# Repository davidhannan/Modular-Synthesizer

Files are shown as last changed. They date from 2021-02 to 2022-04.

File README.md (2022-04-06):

# Modular-Synthesizer

A DIY modular synthesizer.

Made from module circuit designs found from various places online.

Full List of Modules used: [Modules](https://github.com/davidhannan/Modular-Synthesizer/tree/main/Modules) (WIP)

Panel designs made by me in fusion 360 for my 2"x8" module format.
Panels are made from 2"x8"x1/8" aluminum flat bar blanks.

## Update March 24, 2022

How the whole system looks nowadays:


For some reason I thought it would be great if I could start adapting euro modules into my system. Doing so has been quite an adventure in learning how to solder SMD components and learning how to flash a program onto a microcontroller, and to be honest it hasn't been so bad. I actually learned to enjoy it quite a bit! The first one I made was the <a href="https://ornament-and-cri.me/">Ornament and crime</a> which went together pretty smoothly and even started working right away! It can be seen at the very bottom right of the system shot. Next I went for a <a href="https://mutable-instruments.net/modules/braids/">Mutable Instruments Braids</a>. This one wasn't quite as easy as the OC, but I got it working in the end! The main issue I encountered was that I didn't realize that since the PCB that I ordered ended up being for an older version of the module, I had to provide my own +5 volt source to the module along with the +/- 12v that most modules normally require. I ended up throwing together a small 5v regulator using a 7805 and a few capacitors on a piece of stripboard which I hot-glued to the back of board.

Some pictures of the Braids module:



This one shows the 5v regulator that I had to make:


I also have been getting pretty good etching my own PCBs. Heres one for a <a href="http://yusynth.net/Modular/EN/METALIZER/">Yusynth Metalizer</a> that I finished recently. It wasn't finished in the picture but I think it looks great!





## Update February 17, 2022

I never did end up making that fancy cabinet, but I did make two more of the square ones! I filled out one of them and I'm still working on the other. So many new modules in here, too many to list right now. I'll get around to it at some point I'm sure. I even got into some surface mount stuff in here. 

Here is a picture of two full cabinets, featuring my keystep pro sequencer, tape machine/headphone tube amp, and a <a href="https://github.com/davidhannan/Akai-M8-Pre-Mod">mic/guitar pre amp</a> I just finished up.



The inside of cabinet number 2.



## Update June 21, 2021:

The cabinet for stage 2 of my synth system has been designed and it will be made soon. Stage 1 will stack on top of stage 2 for a very cool look. Here is what stage 2 will look like:

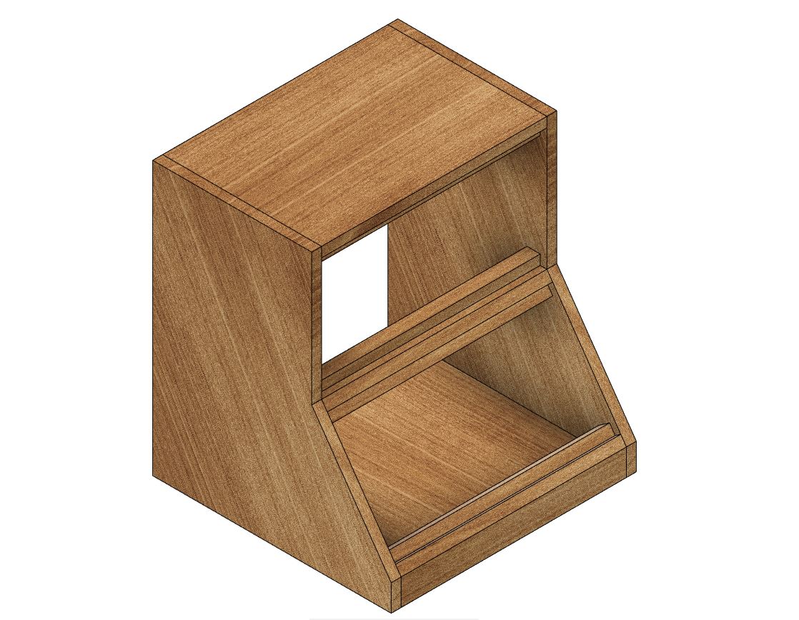
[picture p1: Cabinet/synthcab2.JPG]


## Update June 3, 2021:

Stage 1 is complete! Some pictures of the finished product:











## New as of March 16, 2021:  
Barton Quad VCA Mixer:  
  
PCB purchased from synthcube

## State as of March 8, 2021:  


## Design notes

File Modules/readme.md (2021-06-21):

# List of Modules in Stage 1:

1. 3x VCO from Eddy Bergman. [Link](https://www.eddybergman.com/2020/01/synthesizer-build-part-18-really-good.html)

2. ADSR from Eddy Bergman. [Link](https://www.eddybergman.com/2020/03/synthesizer-build-part-24-adsr-with.html)

3. VCA from Eddy Bergman. [Link](https://www.eddybergman.com/2020/04/synthesizer-build-part-29-vca-yusynth_25.html)

4. Gate/CV Multiple from Eddy Bergman. [Link](https://www.eddybergman.com/2020/03/synthesizer-build-part-25-universal-cv.html)

5. Mixer with passive output from Eddy Bergman. [Link](https://www.eddybergman.com/2020/01/synthesizer-build-part-17-mixer-and.html)

6. VCLFO from Eddy Bergman. [Link](https://www.eddybergman.com/2020/05/synthesizer-build-part-32-electric.html)

7. MS-20 type filter from Eddy Bergman. [Link](https://www.eddybergman.com/2019/12/synthesizer-build-part-12-korg-ms20.html)

8. Resonant Lopass gate from Eddy Bergman. [Link](https://www.eddybergman.com/2020/10/synthesizer-build-part-35-resonant.html)

9. "Safety Valve" from Look Mum No Computer. [Link](https://www.lookmumnocomputer.com/projects#/the-safety-valve)

10. Juno Chorus and Sub Oscillator Combo Module (these are seperate modules but I put them behind the same panel) . [Chorus Link](https://www.dsl-man.de/display/MAIN/Roland+Juno+60+Chorus) | [Sub Osc Link](https://github.com/holmesrichards/subosc)

11. Another multiple module "Euro Multipla" from SyntherJack. I made 2 of these boards, using all ins/outs of one of them and only half of the second one. [Link](https://syntherjack.net/euro-multipla/)

12. Mixer/VCA from Michael Barton. [Link](http://www.bartonmusicalcircuits.com/vcamix/index.html)

13. Simple A/R from Michael Barton. [Link](http://www.bartonmusicalcircuits.com/simplear/index.html)

14. Moog Ladder Filter from Yusynth. [Link](http://yusynth.net/Modular/EN/MOOGVCF/index.html)

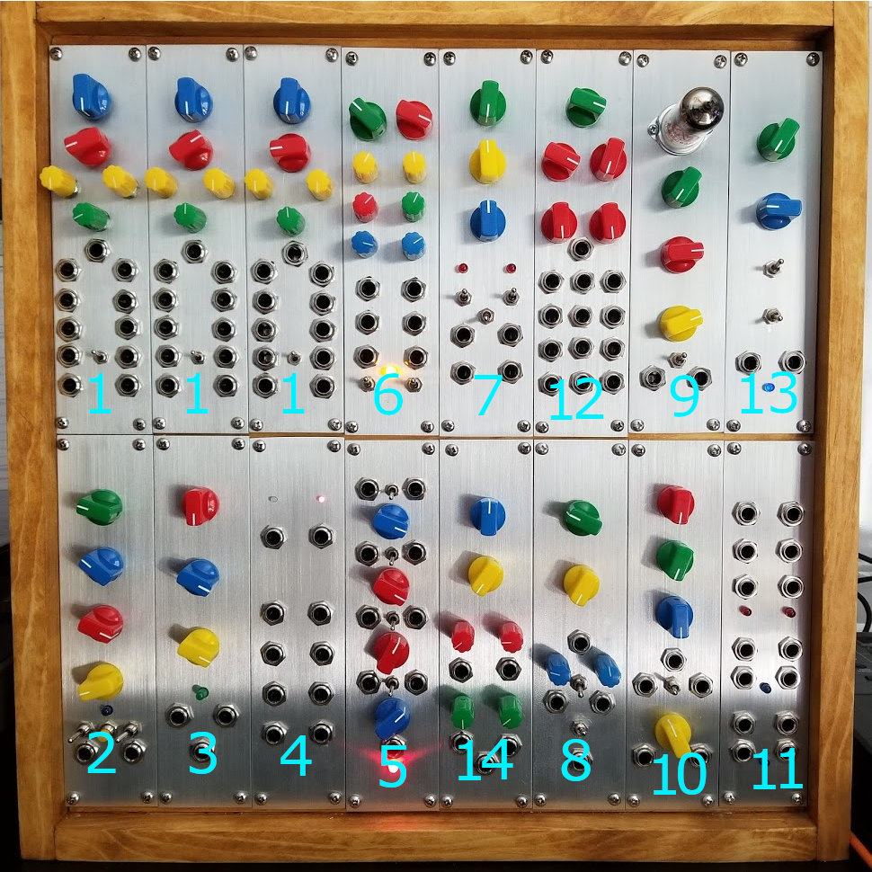
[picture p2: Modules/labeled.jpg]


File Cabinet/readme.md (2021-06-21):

Empty Cabinet:

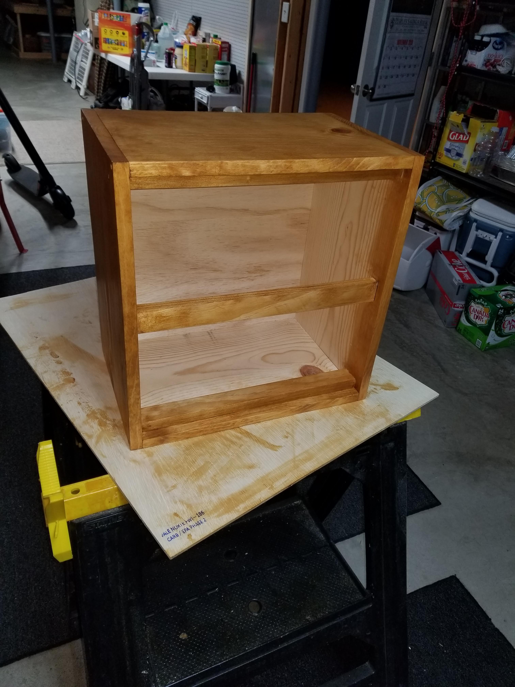
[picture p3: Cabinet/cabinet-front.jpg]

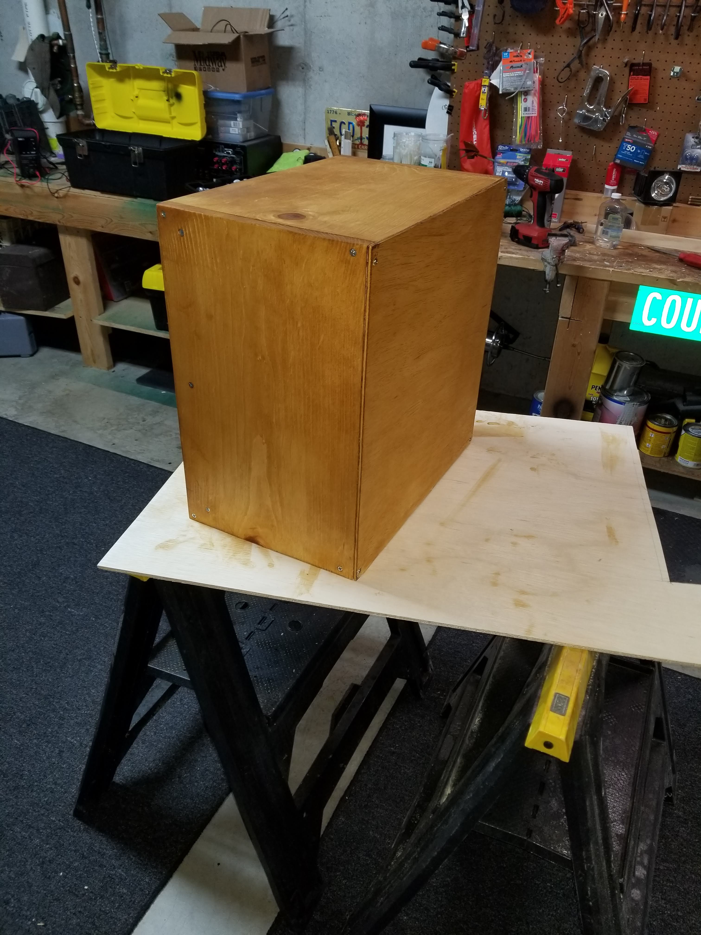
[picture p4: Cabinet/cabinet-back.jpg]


Stage 2 Cabinet CAD:



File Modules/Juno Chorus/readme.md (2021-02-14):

Details of this module can be found <a href="https://www.dsl-man.de/display/MAIN/Roland+Juno+60+Chorus">here</a>

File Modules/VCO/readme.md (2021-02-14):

Empty VCO Panels:

A brushed aluminum finish is achieved by sanding in a jig to ensure uniform sanding direction. An acrylic spray sealant is then applied.

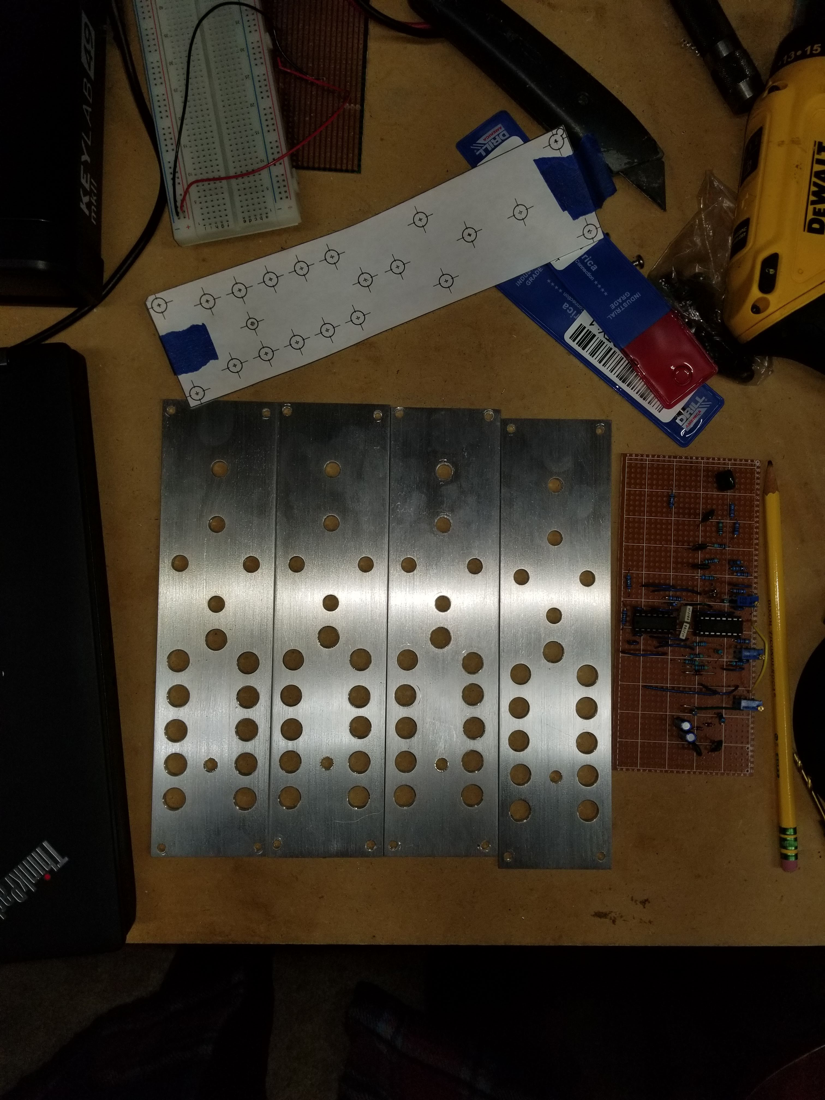
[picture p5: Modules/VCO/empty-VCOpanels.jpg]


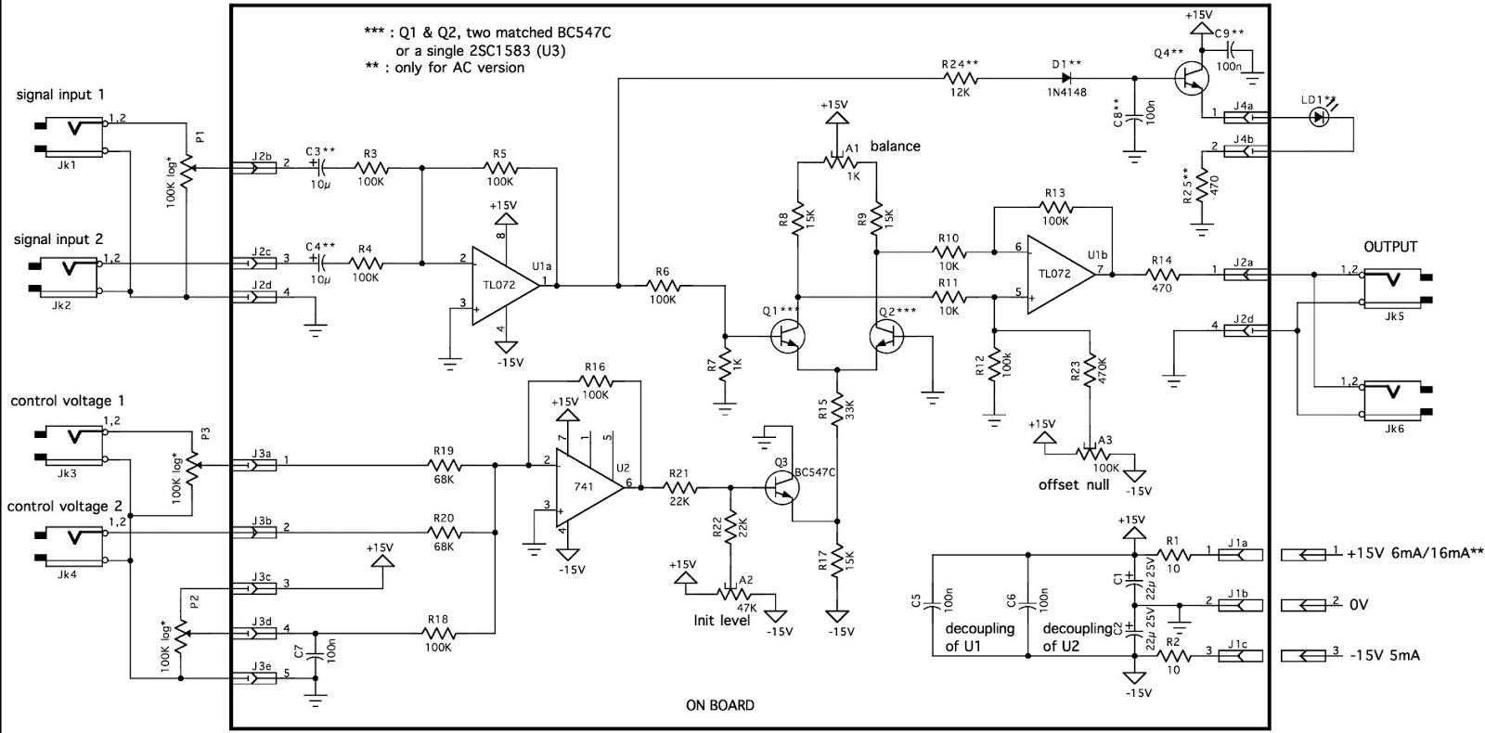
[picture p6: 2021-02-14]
Modules/VCA/VCA Yusynth design new.jpg

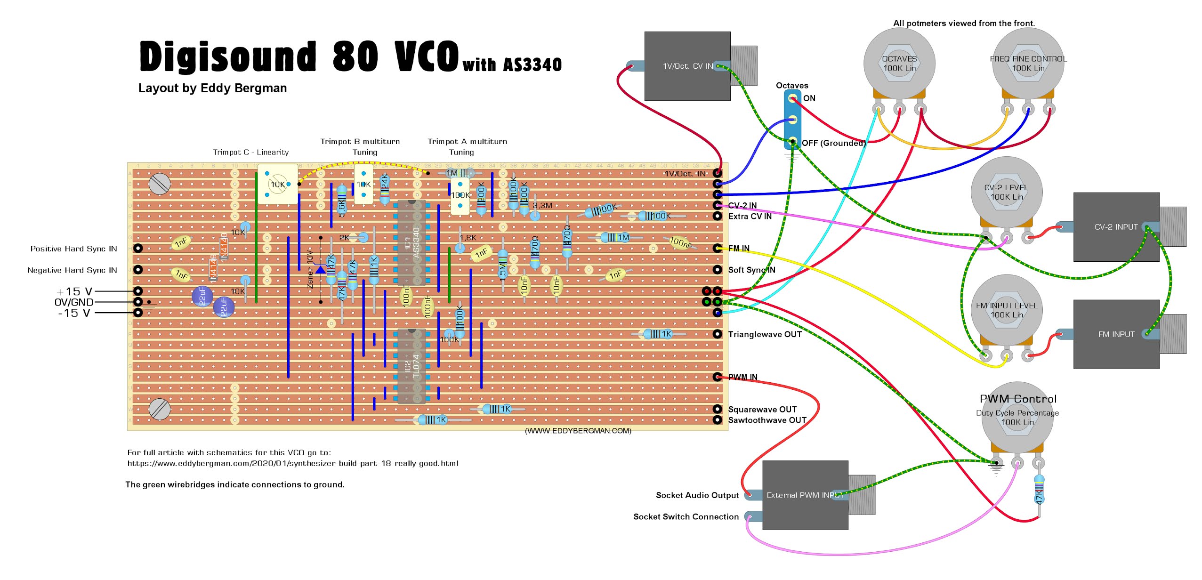
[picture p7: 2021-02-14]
Modules/VCO/Digisound 80 VCO latest w PWM correction.jpg

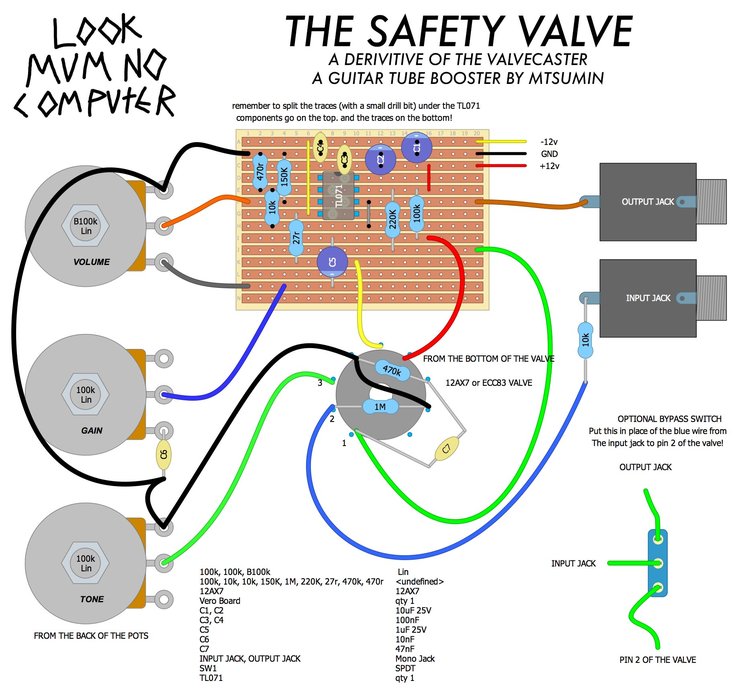
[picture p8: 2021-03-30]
Modules/LMNC safety valve/The+Safety+Valve+Synth+Module.jpg

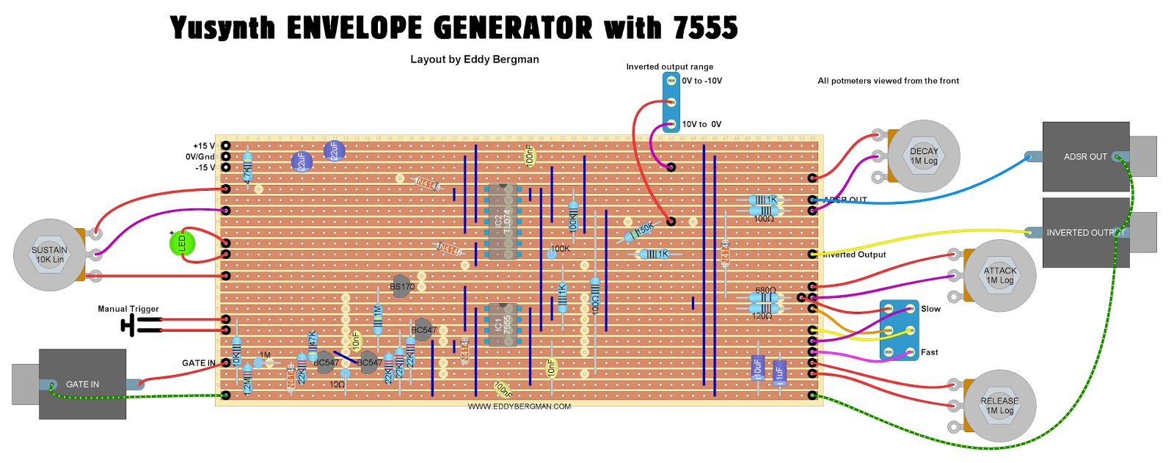
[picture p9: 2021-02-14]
Modules/ADSR/Yusynth ADSR with 7555.jpg

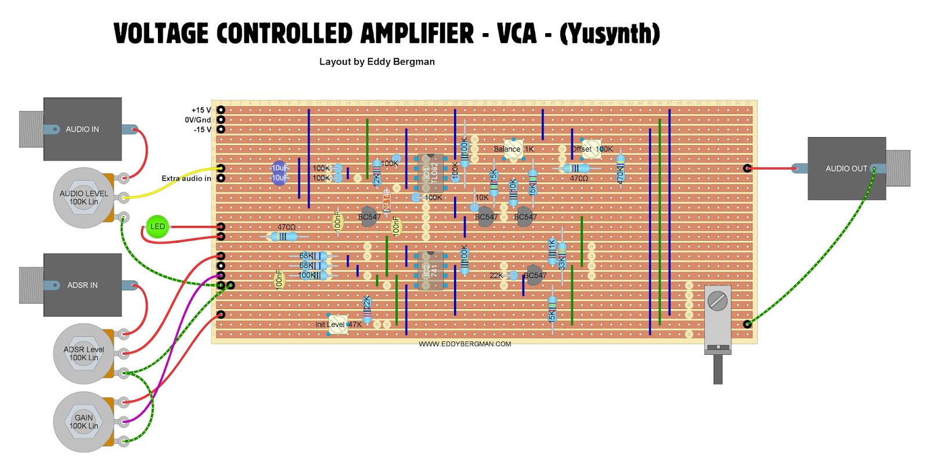
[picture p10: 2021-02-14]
Modules/VCA/VCA-04 yusynth.jpg

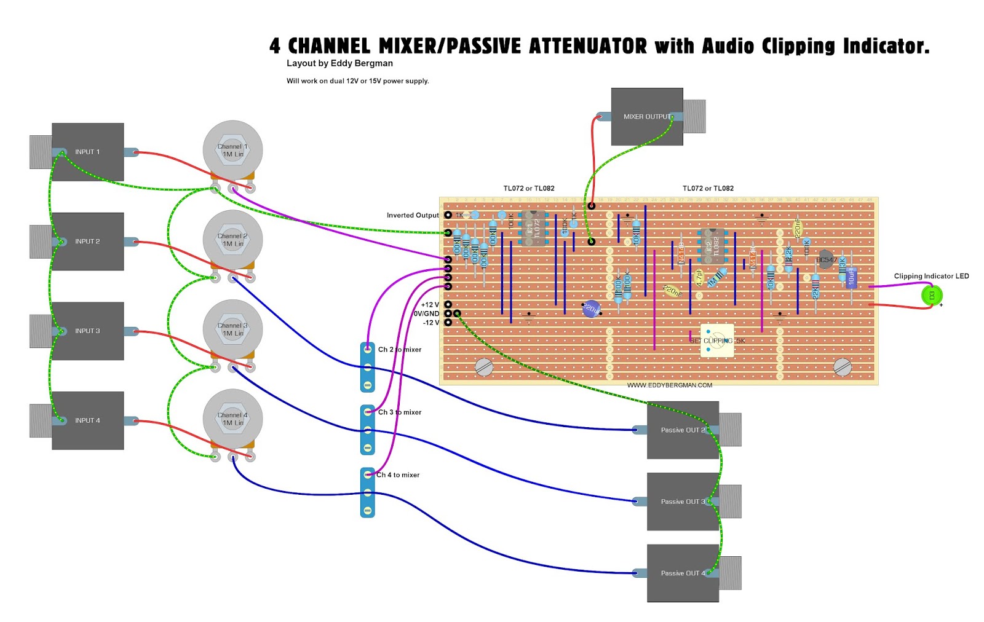
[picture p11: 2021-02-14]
Modules/Mixer/4 Channel Mixer with Clipping Indicator.jpg

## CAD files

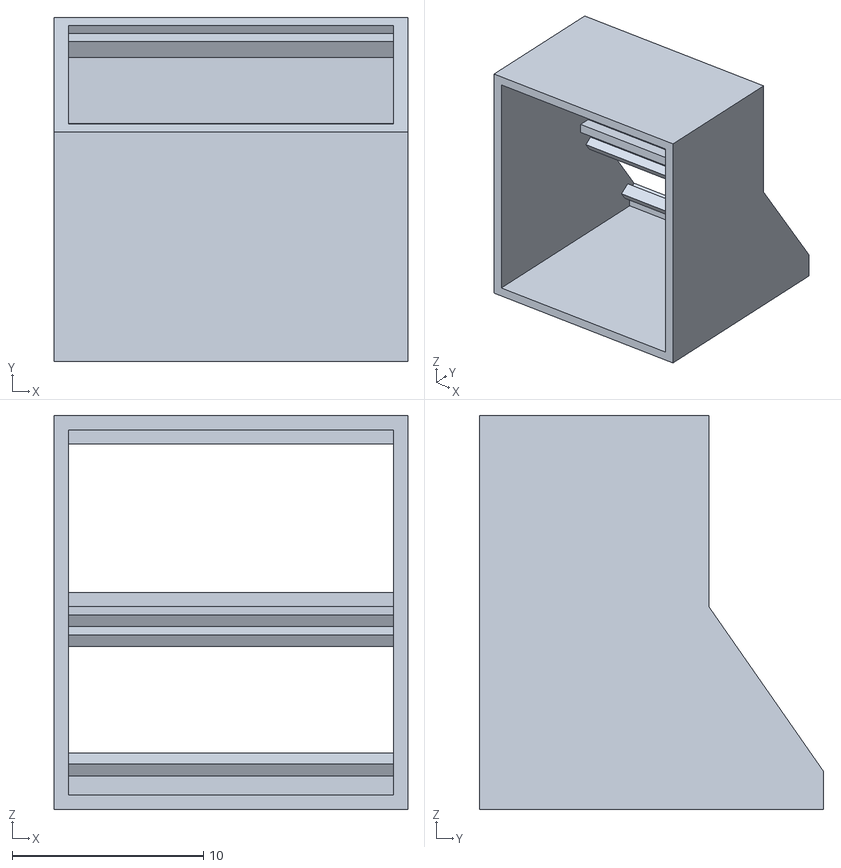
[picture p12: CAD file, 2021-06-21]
Cabinet/cab part 2 comps v3.stl
18.5 x 18.0 x 20.6

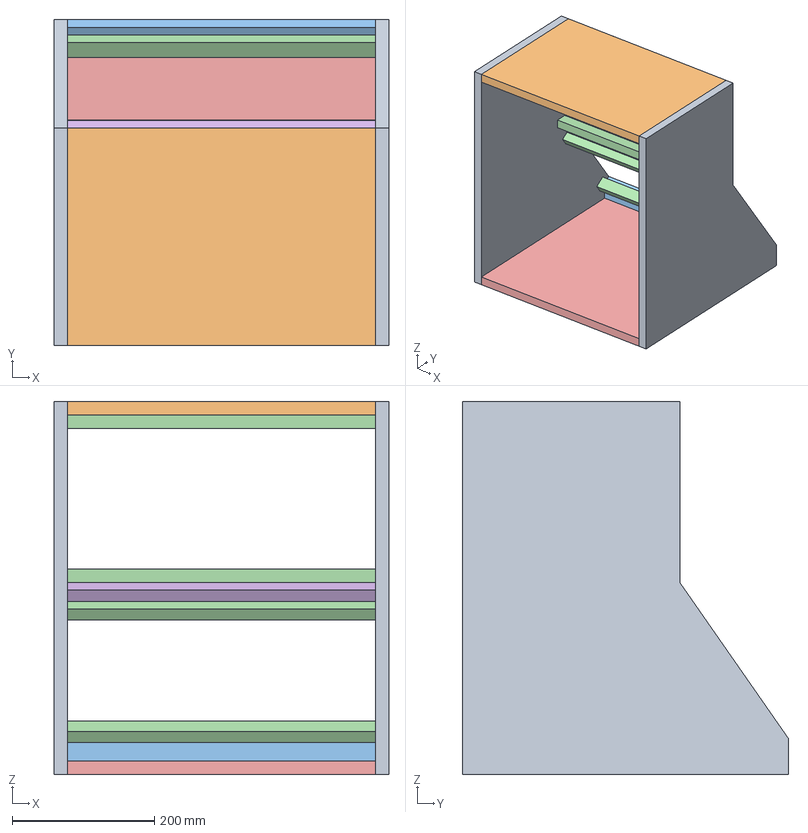
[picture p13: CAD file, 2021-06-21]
Cabinet/synthcabinet2.step
469.9 x 457.2 x 523.7 mm
Right Side
Top
Left Side
Front
Upper Module Section Top Mount
Upper Module Section Bottom Mount
Lower Module Section Top Mount
Lower Module Section Bottom Mount
Bottom
Section Divider

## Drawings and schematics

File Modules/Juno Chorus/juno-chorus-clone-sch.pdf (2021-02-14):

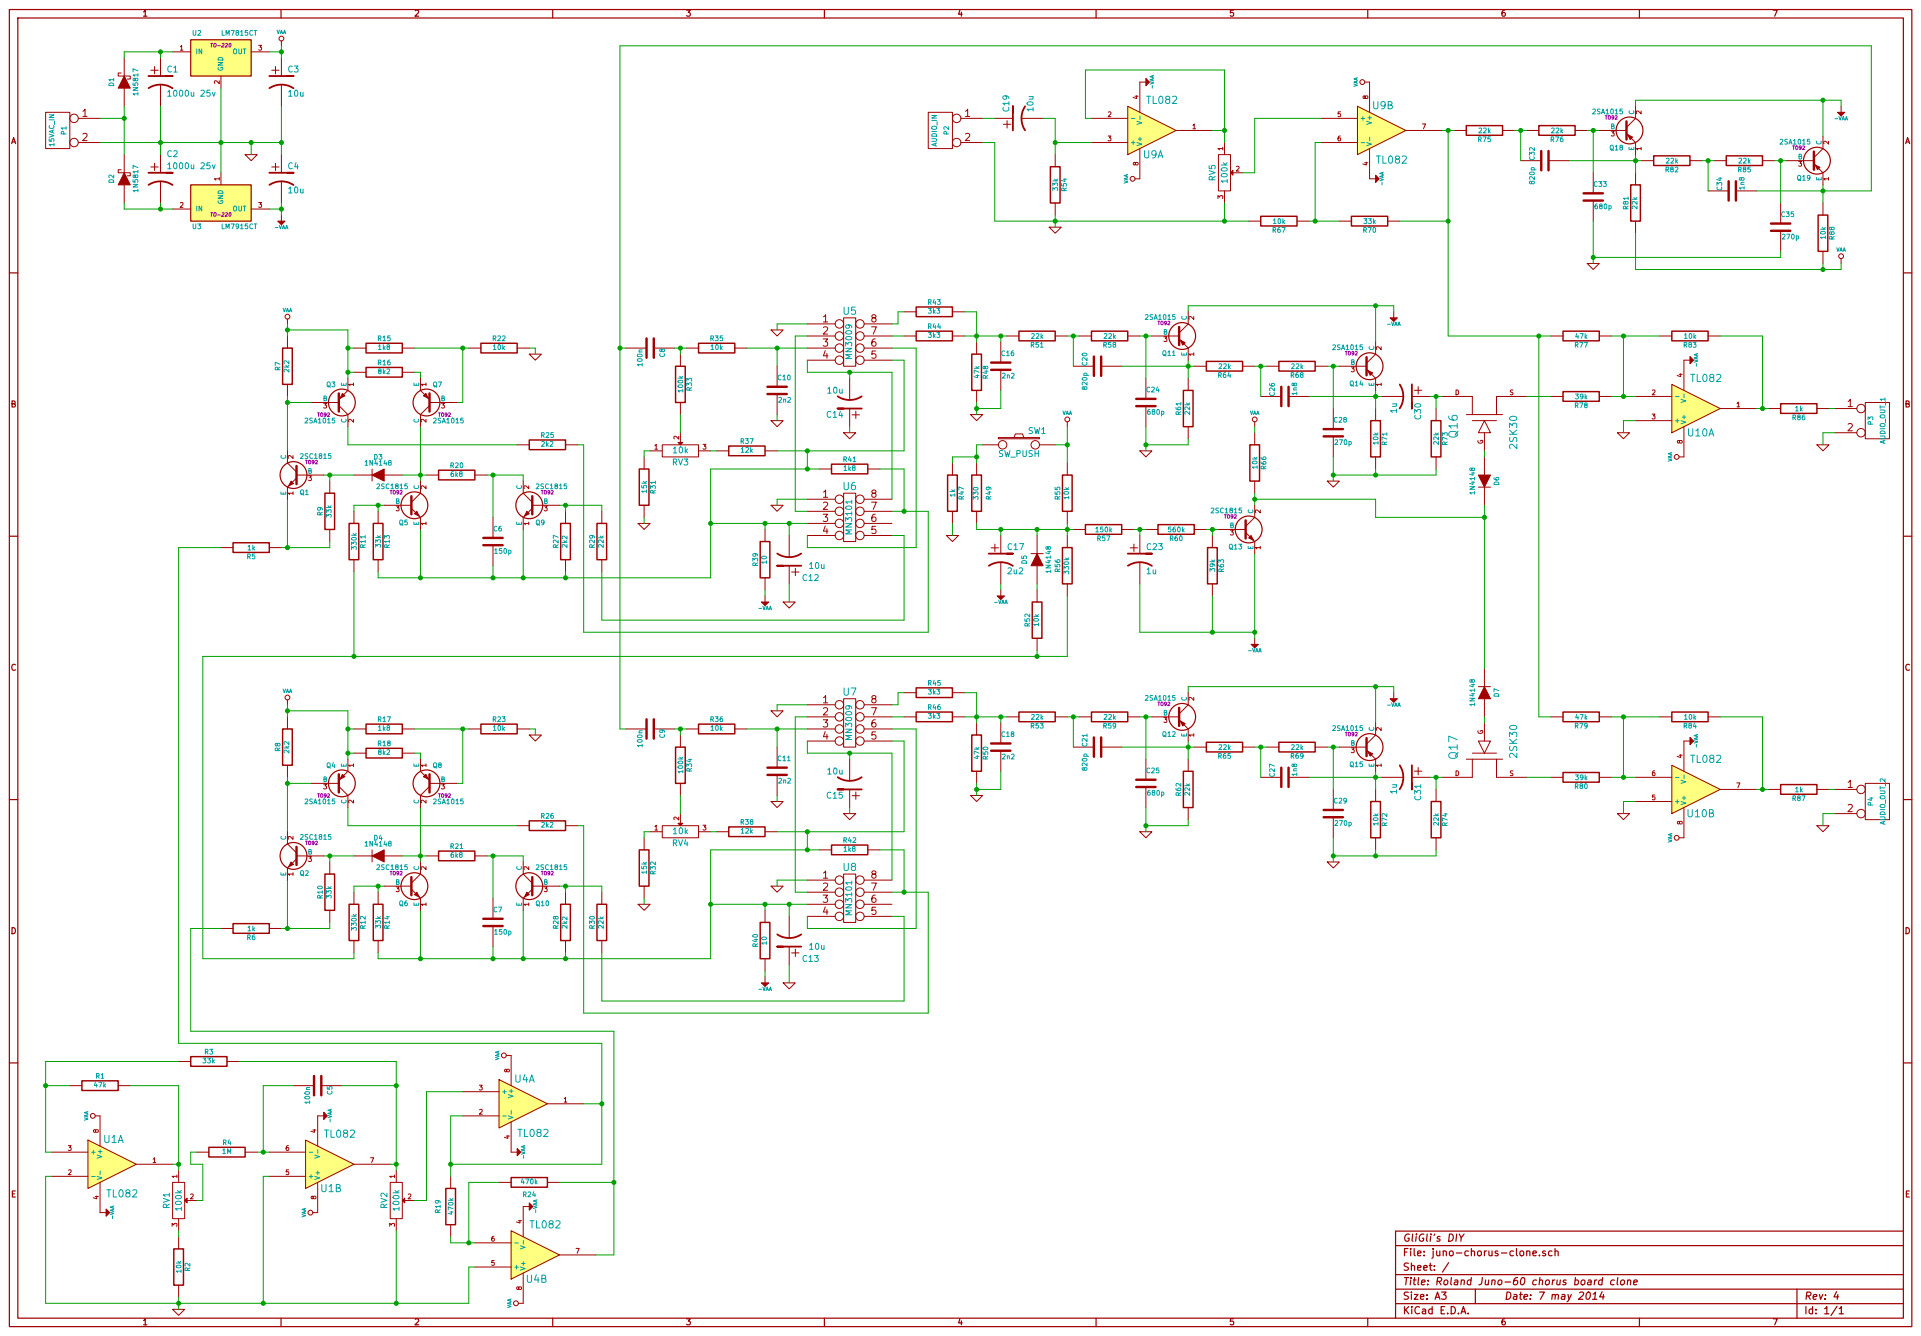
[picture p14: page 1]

GliGli's DIY
Id: 1/1 Title: Roland Juno-60 chorus board clone File: juno-chorus-clone.sch
Sheet: /

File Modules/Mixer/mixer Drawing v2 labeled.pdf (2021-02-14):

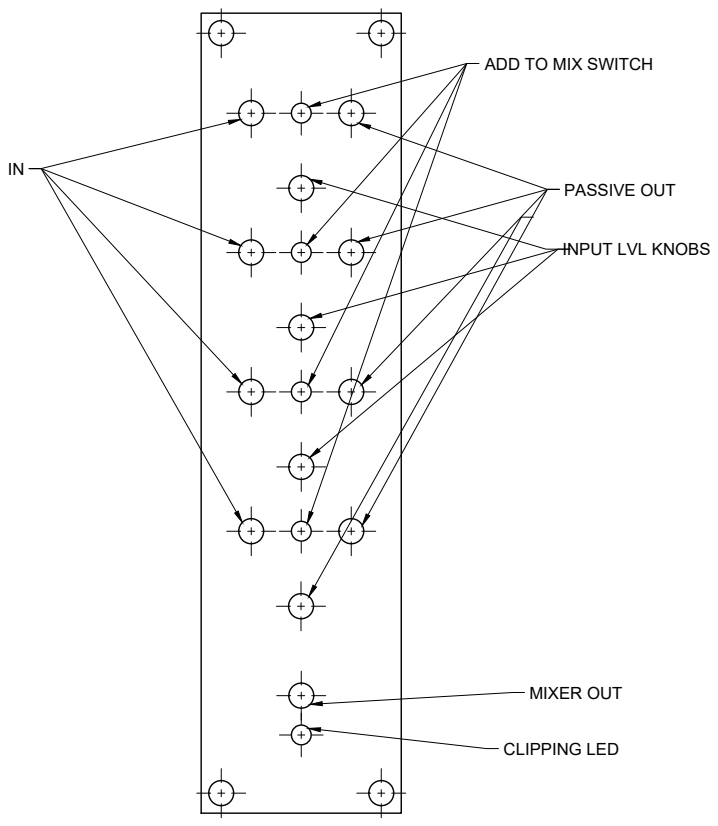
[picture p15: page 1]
PASSIVE OUT; MIXER OUT; CLIPPING LED

ADD TO MIX SWITCH

INPUT LVL KNOBS

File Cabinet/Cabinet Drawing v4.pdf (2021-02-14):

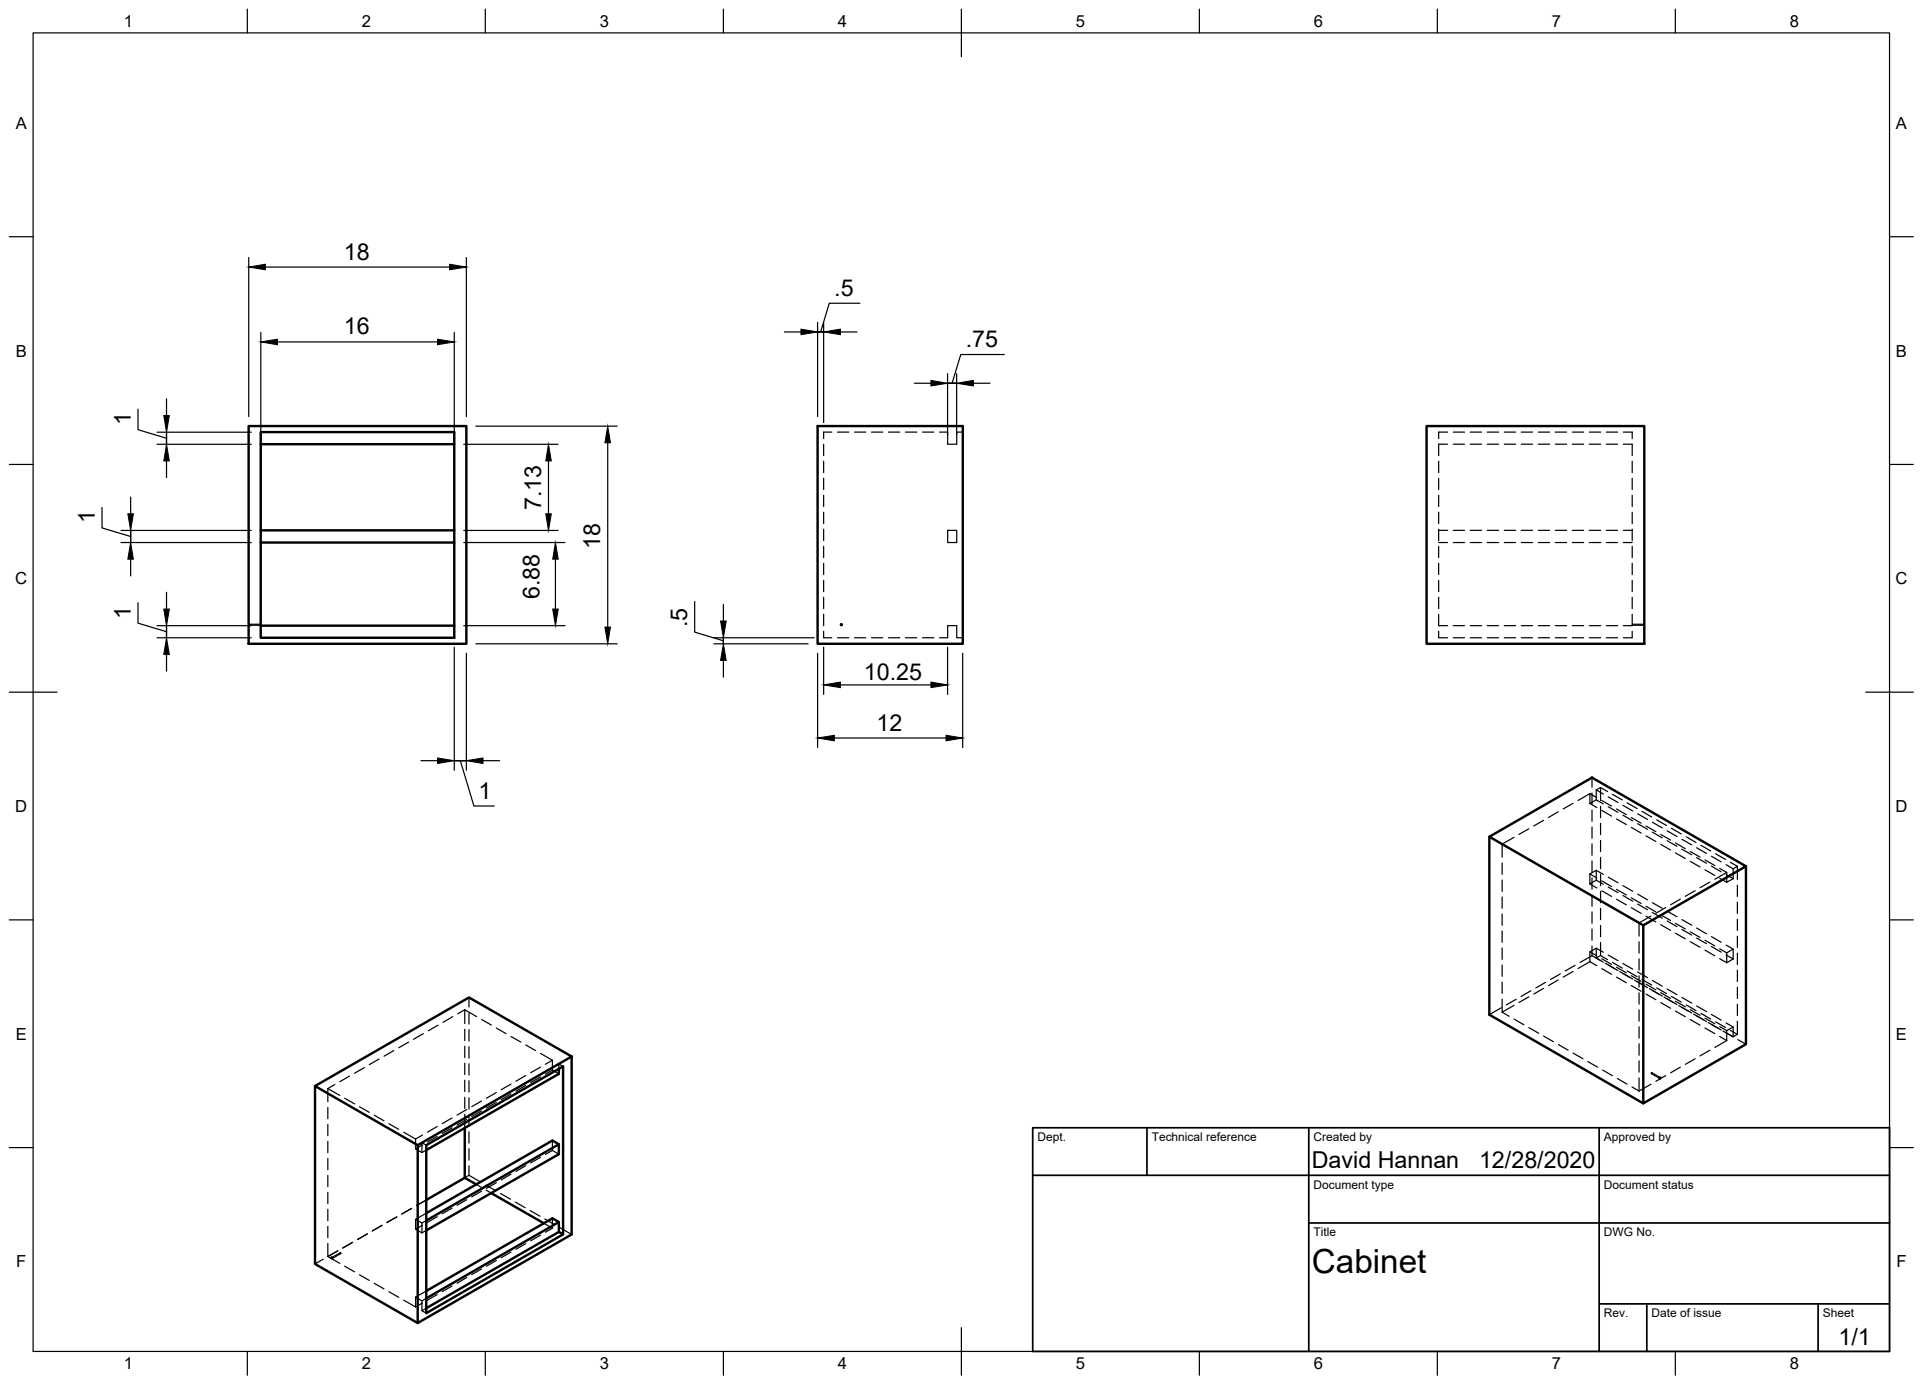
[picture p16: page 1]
Title; DWG No.; Rev.; Date of issue; Sheet

Dept. | Technical reference | Created by David Hannan 12/28/2020 | Approved by

Document type | Document status

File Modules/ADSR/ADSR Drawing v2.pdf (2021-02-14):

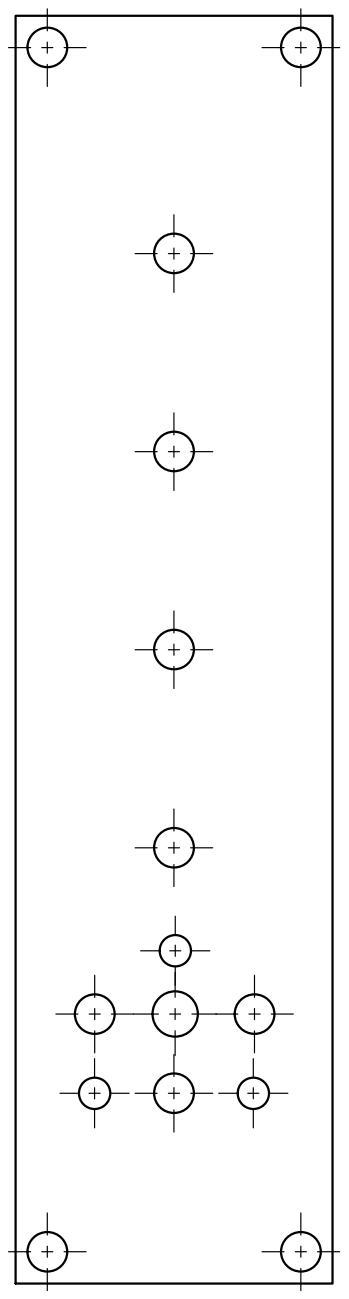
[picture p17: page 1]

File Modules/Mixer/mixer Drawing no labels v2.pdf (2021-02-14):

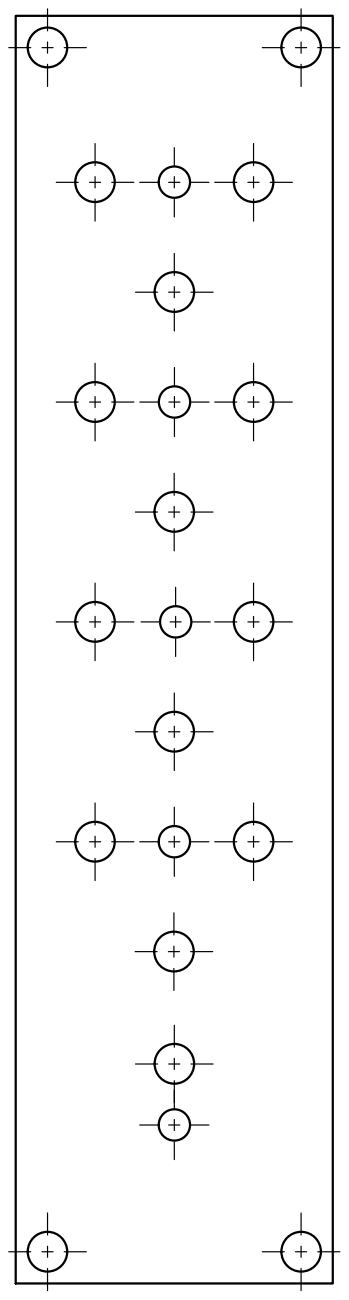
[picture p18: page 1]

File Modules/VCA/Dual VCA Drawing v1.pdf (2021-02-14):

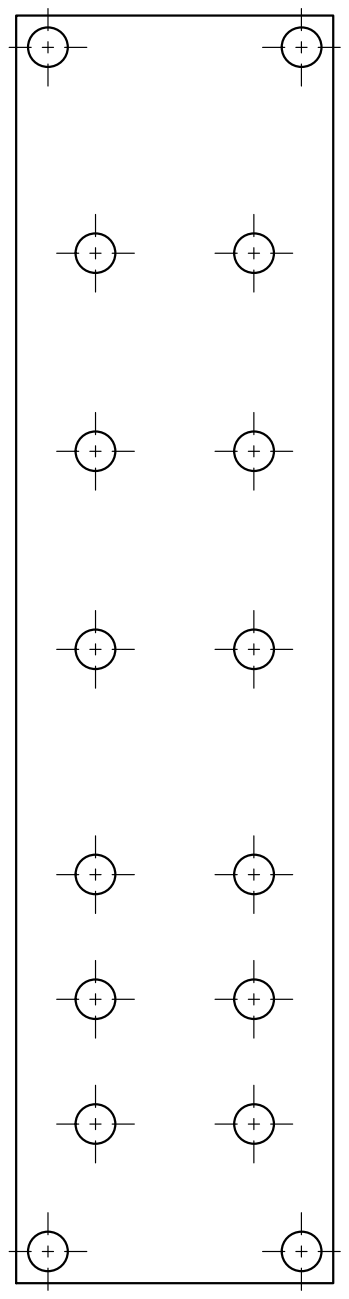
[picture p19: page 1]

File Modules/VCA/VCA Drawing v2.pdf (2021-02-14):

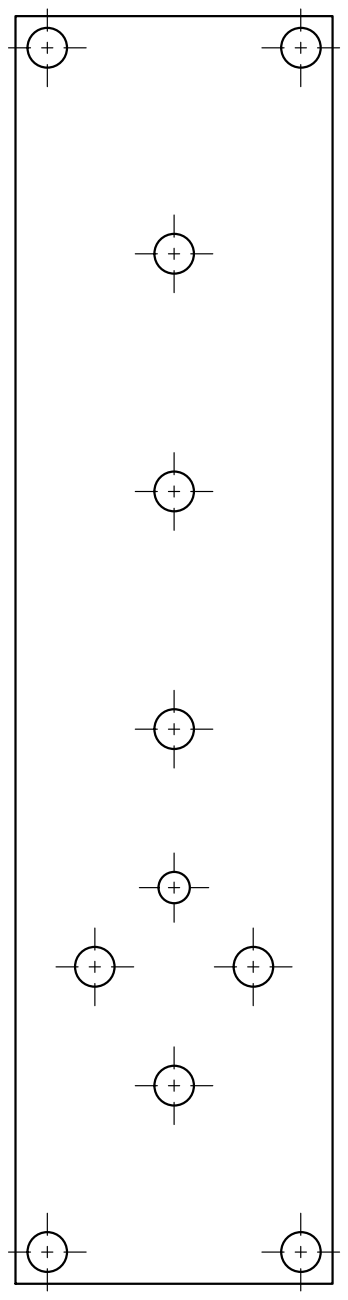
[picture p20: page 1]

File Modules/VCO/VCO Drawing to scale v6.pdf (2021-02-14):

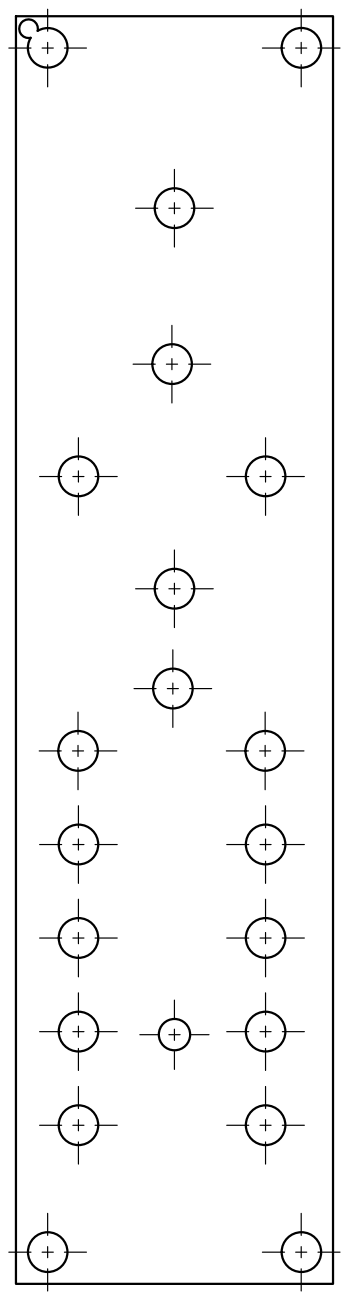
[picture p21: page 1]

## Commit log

2021-03-30 safety valve
2021-06-21 stage 1 done
    [cab part 2 comps v3.step, cab part 2 comps v3.stl, moog ladder layout.kicad_pcb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]
